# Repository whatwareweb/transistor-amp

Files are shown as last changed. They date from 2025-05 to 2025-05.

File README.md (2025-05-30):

# transistor-amp
Simple transistor amplifier for Hack Club Solder 

This amplifier is based on the highly popular LM386 op-amp chip, although it has been somewhat downgraded for the sake of low component count (eg no constant current source, etc)

### Features
 - Class AB for higher efficiency
 - Runs on ~6V (2xCR2032 or external power supply input)
 - Small size, crammed in just over 3 square inches
 - Decent performance in SPICE simulation
   - higher THD than the original IC but not too bad
 - 250mW power output (yeah that's pretty low 😭)

### BOM
| Part | Qty | Notes |
| --- | ----- | --- |
| Battery holder 2032 | 2 | |
| 820uF Capacitor | 1 | |
| Generic diode | 2 | Needs to have 0.7v Vf |
| 5mm terminal block  | 1 | Optional |
| NPN transistor | 5 | I used 2N3904 |
| PNP transistor | 4 | I used 2N3906 |
| 10k potentiometer | 1 | |
| 10k resistor | 2 | |
| 1.5k resistor | 1 | |
| 15k resistor | 1 | |
| 47k resistor | 1 | |
| 220 ohm resistor | 3 | |

### 3d view


### Schematic


### PCB


### Simulation results


slack username: `@whatware`

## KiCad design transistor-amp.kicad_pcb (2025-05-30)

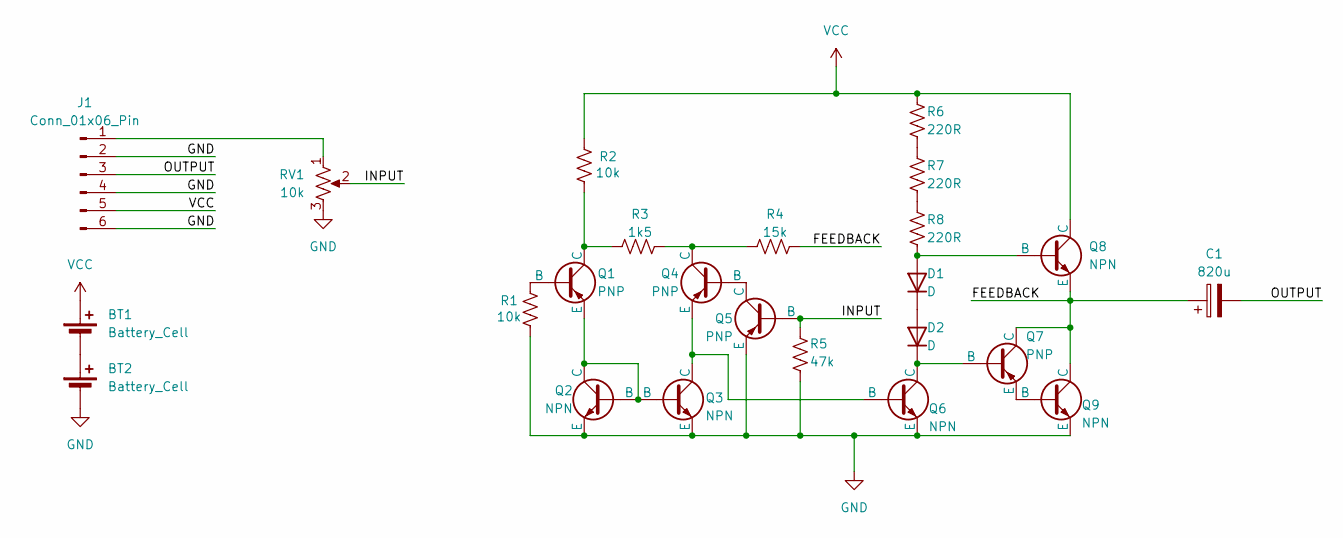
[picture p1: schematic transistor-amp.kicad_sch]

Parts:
BT1, BT2: Battery_Cell; BatteryHolder_Keystone_3034_1x20mm
C1: 820u; CP_Radial_D8.0mm_P3.50mm
D1, D2: D; D_DO-35_SOD27_P10.16mm_Horizontal
J1: Conn_01x06_Pin; TerminalBlock_bornier-6_P5.08mm
Q1, Q4, Q5, Q7: PNP; TO-92L_Inline
Q2, Q3, Q6, Q8, Q9: NPN; TO-92L_Inline
R1, R2: 10k; R_Axial_DIN0207_L6.3mm_D2.5mm_P7.62mm_Horizontal
R3: 1k5; R_Axial_DIN0207_L6.3mm_D2.5mm_P7.62mm_Horizontal
R4: 15k; R_Axial_DIN0207_L6.3mm_D2.5mm_P7.62mm_Horizontal
R5: 47k; R_Axial_DIN0207_L6.3mm_D2.5mm_P7.62mm_Horizontal
R6, R7, R8: 220R; R_Axial_DIN0207_L6.3mm_D2.5mm_P7.62mm_Horizontal
RV1: 10k; Potentiometer_Vishay_T73YP_Vertical

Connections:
/FEEDBACK: C1.1, Q7.1 (C), Q8.3 (E), Q9.1 (C), R4.2
/INPUT: Q5.2 (B), R5.1, RV1.2
/OUTPUT: C1.2, J1.3
GND: BT2.2 (-), J1.2, J1.4, J1.6, Q2.3 (E), Q3.3 (E), Q5.3 (E), Q6.3 (E), Q9.3 (E), R1.2, R5.2, RV1.3
unnamed: BT1.2 (-), BT2.1 (+)
unnamed: D1.2 (A), Q8.2 (B), R8.2
unnamed: D1.1 (K), D2.2 (A)
unnamed: D2.1 (K), Q6.1 (C), Q7.2 (B)
unnamed: J1.1, RV1.1
unnamed: Q1.2 (B), R1.1
unnamed: Q1.1 (C), R2.1, R3.1
unnamed: Q1.3 (E), Q2.1 (C), Q2.2 (B), Q3.2 (B)
unnamed: Q3.1 (C), Q4.3 (E), Q6.2 (B)
unnamed: Q4.2 (B), Q5.1 (C)
unnamed: Q4.1 (C), R3.2, R4.1
unnamed: Q7.3 (E), Q9.2 (B)
unnamed: R6.2, R7.1
unnamed: R7.2, R8.1
VCC: BT1.1 (+), J1.5, Q8.1 (C), R2.2, R6.1

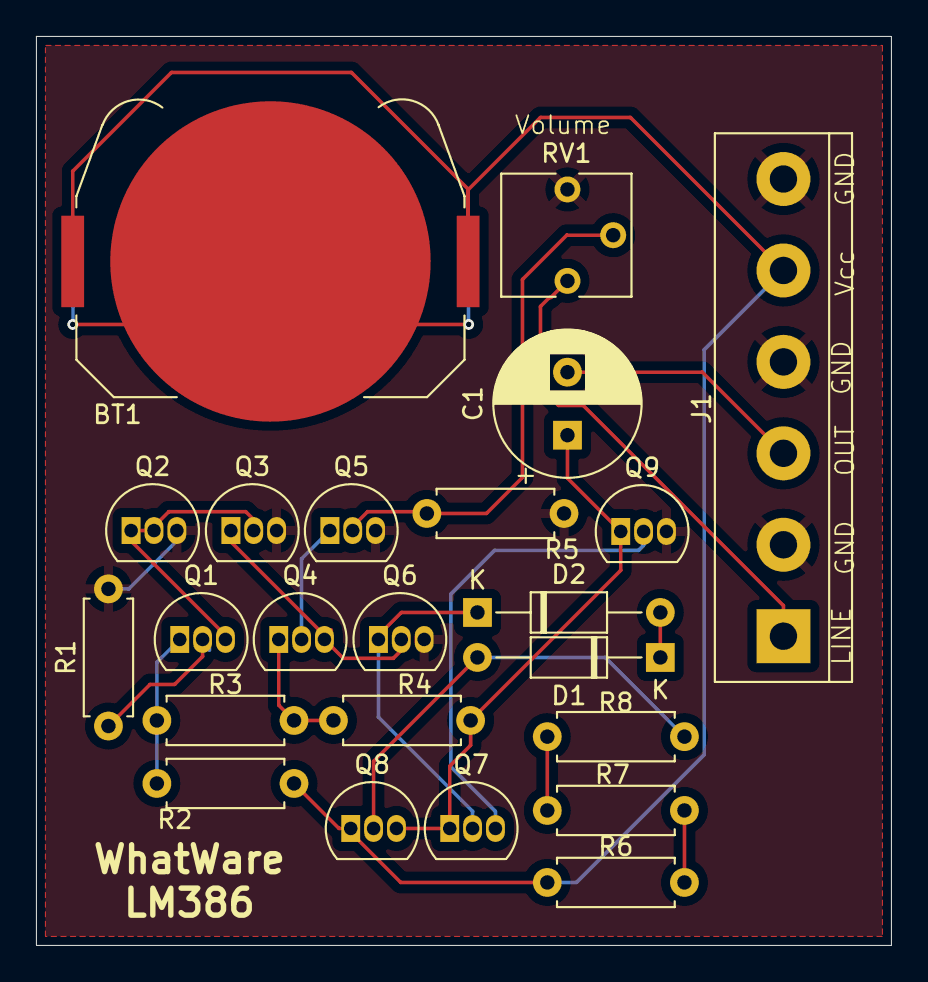
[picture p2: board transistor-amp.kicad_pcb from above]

Board: 2 copper layers, 47.5 x 50.5 mm, 24 parts (1 on the bottom side), 19 nets.

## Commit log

2025-05-15 create kicad project
    [transistor-amp.kicad_pcb, transistor-amp.kicad_sch]
2025-05-30 finish schematic+pcb
    [transistor-amp.kicad_pcb, transistor-amp.kicad_sch]
2025-05-30 add gerber/drill files
    [transistor-amp-B_Cu.gbr, transistor-amp-B_Mask.gbr, transistor-amp-B_Silkscreen.gbr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]
